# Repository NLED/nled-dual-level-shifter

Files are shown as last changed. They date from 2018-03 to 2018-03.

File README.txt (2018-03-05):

THERE IS NO WARRANTY FOR THE PROGRAM, TO THE EXTENT PERMITTED BY APPLICABLE LAW. 
EXCEPT WHEN OTHERWISE STATED IN WRITING THE COPYRIGHT HOLDERS AND/OR OTHER PARTIES 
PROVIDE THE PROGRAM “AS IS” WITHOUT WARRANTY OF ANY KIND, EITHER EXPRESSED OR IMPLIED,
INCLUDING, BUT NOT LIMITED TO, THE IMPLIED WARRANTIES OF MERCHANTABILITY AND FITNESS 
FOR A PARTICULAR PURPOSE. THE ENTIRE RISK AS TO THE QUALITY AND PERFORMANCE OF THE 
PROGRAM IS WITH YOU. SHOULD THE PROGRAM PROVE DEFECTIVE, YOU ASSUME THE COST OF ALL 
NECESSARY SERVICING, REPAIR OR CORRECTION.

 Original Author: Jeffrey Nygaard
 Company: Northern Lights Electronic Design, LLC
 Date: March 5, 2018
 Contact: JNygaard@NLEDshop.com
 Copyright© 2018 by Northern Lights Electronic Design, LLC. All Rights Reserved
 
;=============          www.NLEDShop.com/addoncards           ============
;=============     www.NorthernLightsElectronicDesign.com       ============

This work is licensed under a Attribution-NonCommercial 4.0 International (CC BY-NC 4.0)
https://creativecommons.org/licenses/by-nc/4.0/legalcode

Free to use for personal use, but please attribute the original author.

Commercial licenses versions are available for a donation of any amount. Contact JNygaard@NLEDshop.com for details.

================================================================================================================

Ready-made devices are available for purchase, and large batch manufacturing of any device can be requested.
Please see the webpage www.NLEDShop.com/pixelproducts

NLED is available for custom design and manufacturing, please contact via phone or email to discuss your project.

================================================================================================================

This dual channel level translator(shifter) is used to convert 3.3 volt signals to 5 volt signals. It features 
on-board low drop out linear regulators for both the 5 volt and 3.3 volt rails. That allows it to support a VIN 
of up to 12 volts, which makes it easy to connect to other devices. The TXS0102 I.C. allows speeds up to 24Mbps, 
designed specifically for addressable LED pixels which utilize clock and data lines, or other types of SPI based 
communication. The layout of the board allows it to be used inline with standard wiring for adressable pixels, 
no tricky wiring or jumping.

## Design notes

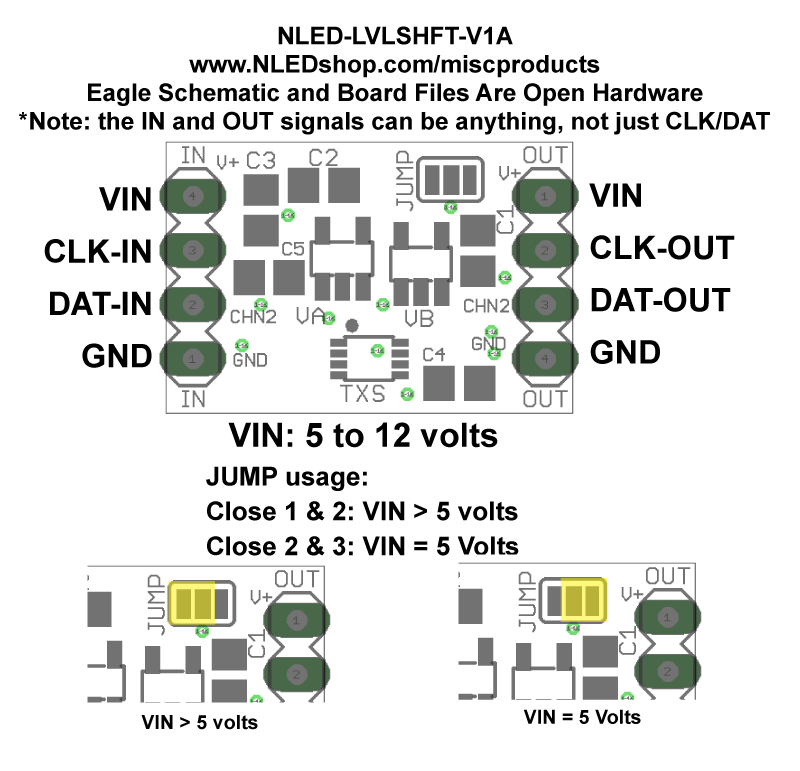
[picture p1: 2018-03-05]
nled-lvlshft-v1a-diagram.png

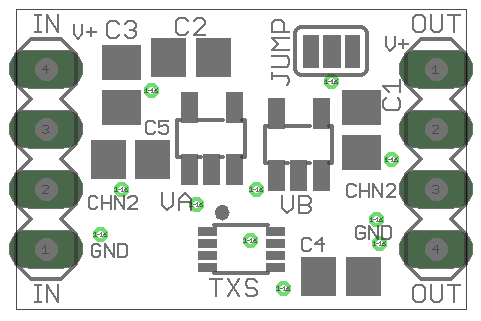
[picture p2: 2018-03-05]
nled-lvlshft-v1a-graphic.png

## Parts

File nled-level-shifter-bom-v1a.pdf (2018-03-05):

Sheet1

Page 1

V1A

Part | Description | Package | Per Kit | Part ID | Cost Per Part
PCB | 0.5” x 0.75” | | 1 | | $0.99
VREG A | 3.3v, LDO | SOT-23-5 | 1 | VA | $0.21
VREG B | 5v, LDO | SOT-23-5 | 1 | VB | $0.18
Level Translator | 2-bit, bidirectional | VSSOP-8 | 1 | TXS | $0.53
Decouple Cap | 6.3v, 0.1uF | 0805 | 3 | C3,C4,C5 | $0.05 | standard
Bypass Cap | 6.3v, 0.01uF | 0805 | 2 | C1,C2 | $0.02
| | | | | $1.98 | Seeed
| | | | | | AP2210K-3.3TRG1 (http://www.mouser.com/ProductDetail/Diodes-Incorporated/AP2210K-33TRG1/)
| | | | | | AP2210K-5.0TRG1 (http://www.mouser.com/ProductDetail/Diodes-Incorporated/AP2210K-50TRG1/)
| | | | | | TXS0102DCUR (http://www.mouser.com/ProductDetail/Texas-Instruments/TXS0102DCUR/)
| | | | | | VJ0805A101GXXCW1BC (http://www.mouser.com/Search/ProductDetail.aspx)

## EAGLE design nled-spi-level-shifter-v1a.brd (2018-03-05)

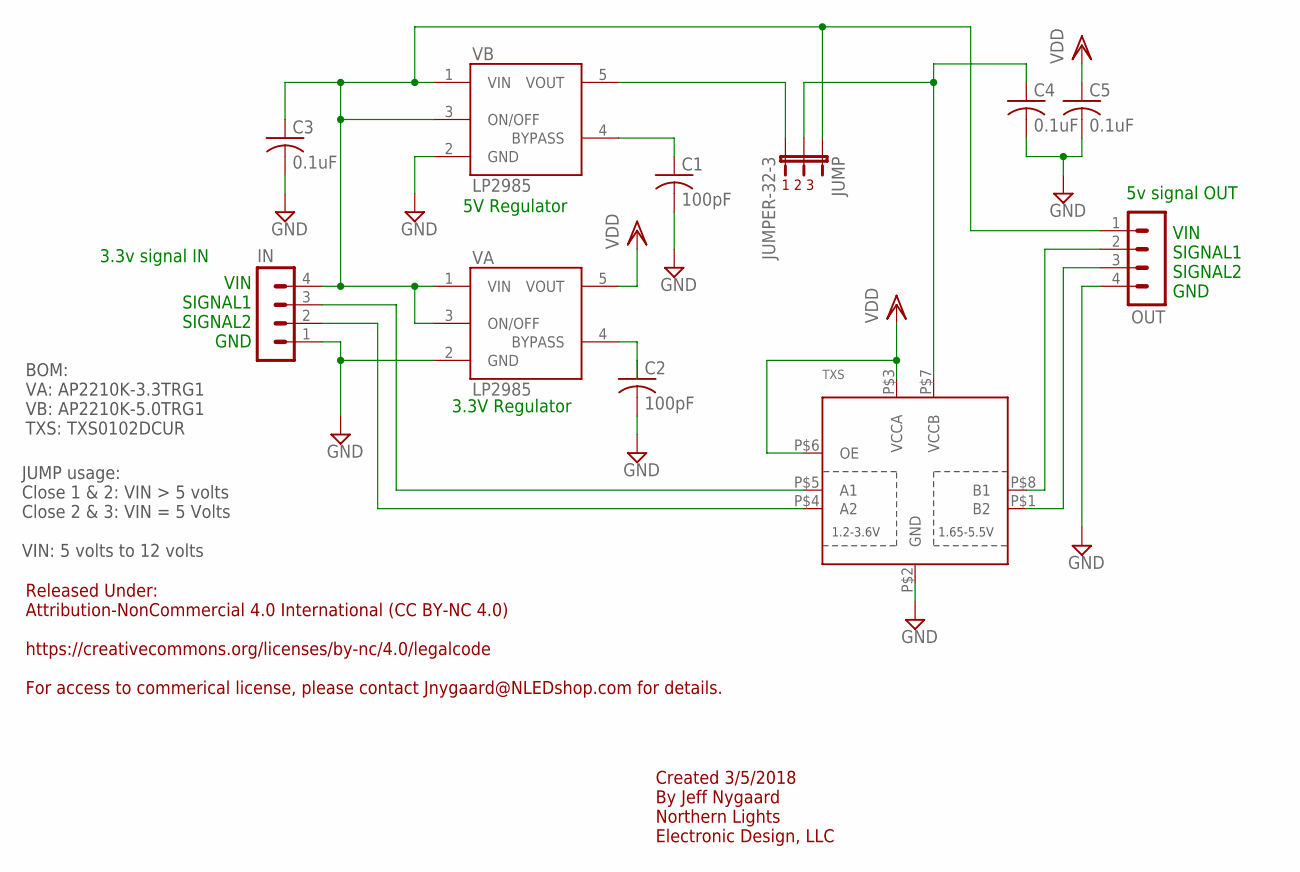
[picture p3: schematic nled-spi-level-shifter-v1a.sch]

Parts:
C1, C2: 100pF; C0805
C3, C4, C5: 0.1uF; C0805
IN: MA04-1
JUMP: JUMPER-32-3; SJ_3_PASTE2&3
OUT: MA04-1
TXS: TXS0102; VFSOP-8
VA: LP2985AIM5-3.3; SOT25
VB: LP2985AIM5-3.3; SOT25

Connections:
BYPASS: C1.1, VB.4 (BYPASS)
BYPASSB: C2.1, VA.4 (BYPASS)
GND: C1.2, C2.2, C3.2, C4.2, C5.2, IN.1, OUT.4, TXS.P$2 (GND), VA.2 (GND), VB.2 (GND)
unnamed: C4.1, JUMP.2, TXS.P$7 (VCCB)
unnamed: IN.3, TXS.P$5 (A1)
unnamed: IN.2, TXS.P$4 (A2)
unnamed: OUT.2, TXS.P$8 (B1)
unnamed: OUT.3, TXS.P$1 (B2)
unnamed: JUMP.3, VB.5 (VOUT)
VDD: C5.1, TXS.P$3 (VCCA), TXS.P$6 (OE), VA.5 (VOUT)
VIN: C3.1, IN.4, JUMP.1, OUT.1, VA.1 (VIN), VA.3 (ON/OFF), VB.1 (VIN), VB.3 (ON/OFF)

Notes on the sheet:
3.3v signal IN
5v signal OUT
Released Under: Attribution-NonCommercial 4.0 International (CC BY-NC 4.0) https://creativecommons.org/licenses/by-nc/4.0/legalcode For access to commerical license, please contact Jnygaard@NLEDshop.com for details.
Created 3/5/2018 By Jeff Nygaard Northern Lights Electronic Design, LLC
3.3V Regulator
5V Regulator
1 2 3
JUMP usage: Close 1 & 2: VIN > 5 volts Close 2 & 3: VIN = 5 Volts VIN: 5 volts to 12 volts
BOM: VA: AP2210K-3.3TRG1 VB: AP2210K-5.0TRG1 TXS: TXS0102DCUR
VIN SIGNAL1 SIGNAL2 GND

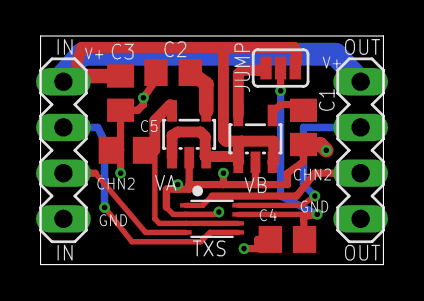
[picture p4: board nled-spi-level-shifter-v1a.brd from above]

Board: 2 copper layers, 19.1 x 12.7 mm, 11 parts (0 on the bottom side), 11 nets.

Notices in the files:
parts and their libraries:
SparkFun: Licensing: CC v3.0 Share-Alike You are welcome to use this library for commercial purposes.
